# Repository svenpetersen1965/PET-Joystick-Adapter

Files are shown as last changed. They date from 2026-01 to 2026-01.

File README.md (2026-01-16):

# PET-Joystick-Adapter
A C64/VIC-20/Atari Joystick Adapter for the Commodore PET. It supports the Coyote Electronics pin configuration (two joysticks) and the space invader/break put style pin configuration (left, right, fire), found on zimmers.net (https://www.zimmers.net/anonftp/pub/cbm/pet/games/english/joy/index.html).

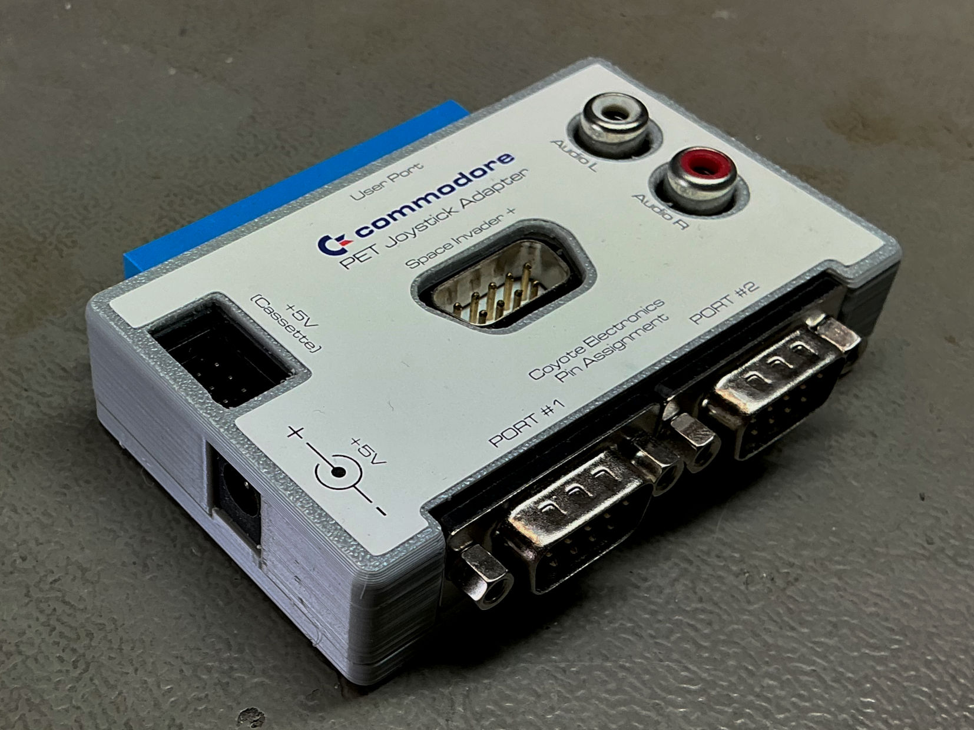
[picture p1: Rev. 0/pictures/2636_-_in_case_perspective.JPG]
PET Joystick Adapter


The Coyote Electronics pin configuration is also called "PET User port adapter" in the VICE emulator, so it is expected to be wide spread. Space Invader + is the completed pin configuration of the previously mentioned games and can also be found on the "stupid PET tricks" adapter. Hence the name. 
All joystick games found in the previously mention source could be played with this joystick adapter.

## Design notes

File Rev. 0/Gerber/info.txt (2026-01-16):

      
       Board: PET_Joystick_Adapter
       Rev.:  0
  
       Files:
       ======
  
       All Gerber files are generated in extended gerber format (RS274X)
       *.TOP        : Film top copper
       *.BOT        :  -"- bottom copper
       *.STC        :  -"- top soldermask 
       *.STS        :  -"- bottom soldermask
       *.PLC        :  -"- silk screen top
       *.PLS        :  -"- silk screen bottom 
       *.DK         : Drills plated Through (Excellon)
       *.NDK        : Drills not plated Through (Excellon)
       *.OUT        : Board outline

       Board Size:
       ===========
       Length     :   77.0 mm
       Width      :   48.0 mm
       Thickness  :   1.6 mm
       Material   :   FR 4
       Copper     :   35 um
       Surface    :   HASL
       
       Remarks:
       ========
       Width >= 8mil
       Distance >= 6mil
       Drill >= 0.35mm

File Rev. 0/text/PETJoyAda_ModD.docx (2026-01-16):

Commodore PET Joystick Adapter Rev. 0

Module Description

# 1 Introduction

This is an adapter for connecting the widespread Commodore C64 or Atari Joysticks to the user port of the PET series computers.

There is no real standard for doing so, thus the most common pin assignments at the user port had to be determined. The main source was the website zimmers.net. The document https://www.zimmers.net/anonftp/pub/cbm/documents/projects/interfaces/pet_joystick.txt shows a pin assignment, that was used for most joystick games, that could be found on the website (https://www.zimmers.net/anonftp/pub/cbm/pet/games/english/joy/index.html). This pin assignment is also found at the original “Coyote Electronics“ joystick adapter“ and it is the one that is used for the „PET“ joystick emulation in the VICE PET emulator.

There is a further pin assignment for „left/right/fire“ games, that can also be found on the said website, which is not identical to the first pin assignment. The up/down directions are not defined for most of those games, except “leap frog fix.prg”. The found pin configuration was confirmed by „Stupid PET tricks“ adapter. There it is called “Space Invader +”, thus the name.

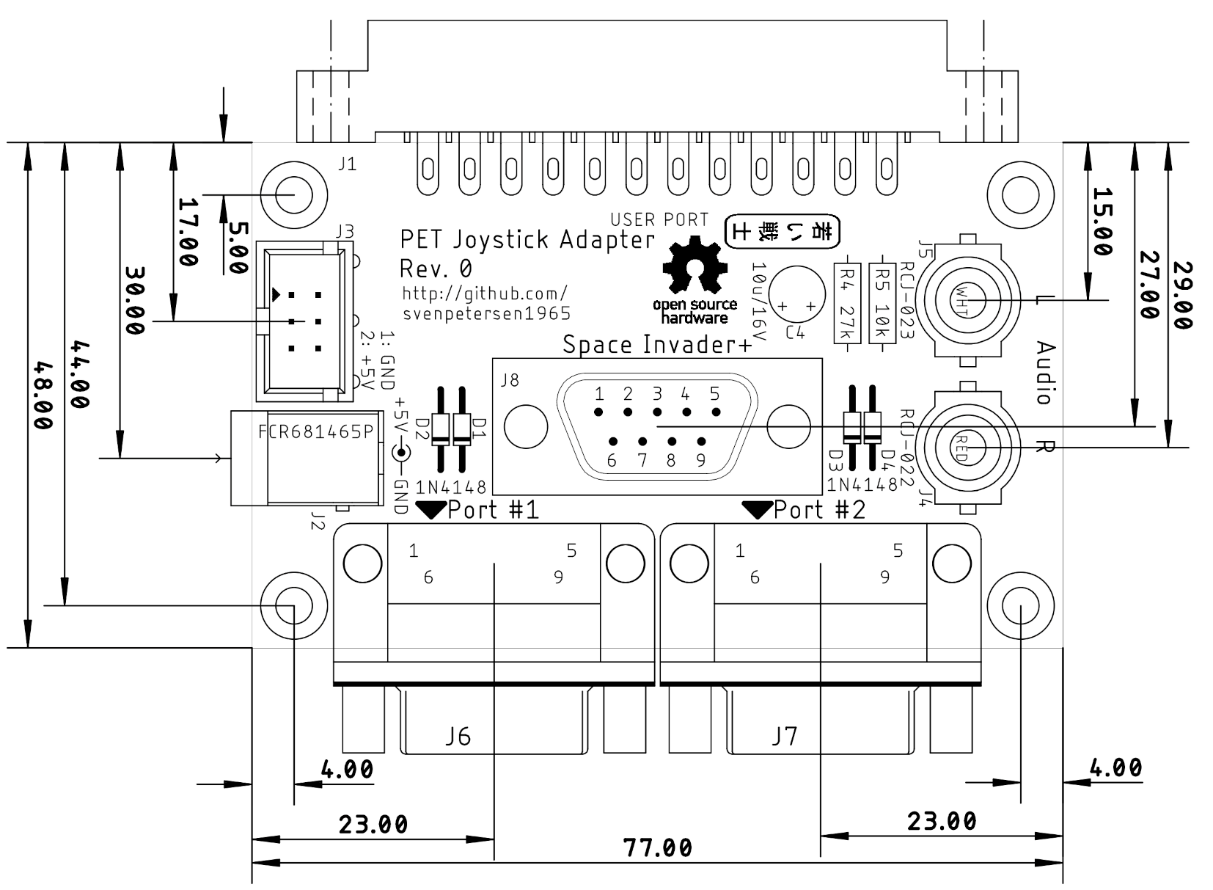
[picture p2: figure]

Figure 1: Dimensions of the PCB

# 2 Pin Assignments

## 2.1 Coyote Electronics

Port | D-Sub Pin | Direction | User Port | Pin
1 | 1 | Up | PA0 | C
| 2 | Down | PA1 | D
| 3 | Left | PA2 | E
| 4 | Right | PA3 | F
| 6 | Fire | PA0 & PA1 (Diodes) | C & D
| 7 | +5V | Not available | -
| 8 | GND | GND | 1, 12, A, N
2 | 1 | Up | PA4 | H
| 2 | Down | PA5 | J
| 3 | Left | PA6 | K
| 4 | Right | PA7 | L
| 6 | Fire | PA4 & PA5 (Diodes) | H & J
| 7 | +5V | Not available | -
| 8 | GND | GND | 1, 12, A, N

## 2.2 Space Invader +

D-Sub Pin | Direction | User Port | Pin
1 | Up | PA2 | E
2 | Down | PA3 | F
3 | Left | PA0 | C
4 | Right | PA1 | D
6 | Fire | PA4 & PA5 (Diodes) | H & J
7 | +5V | Not available | -
8 | GND | GND | 1, 12, A, N

# 3 Further Features

## 3.1 Power Supply

The +5V supply voltage is usually not required, it only serves for powering auto-fire circuits. There are two ways of powering the adapter:

- From the cassette port with the Diagnostic cassette port dongle (https://github.com/svenpetersen1965/C64-Diagnostic-Rev.-586220-Harness/tree/master/Diag586220_Harness/Diag586220_Cassette_Port)
- Via the barrel connector (5.5mm/2.5mm).

## 3.2 Cassette Port Connector

Pin | Signal | Signal | Pin
1 | GND | +5V | 2
3 | n.c. | n.c. | 4
5 | n.c. | n.c. | 6

## 3.3 Barrel Connector

5.5mm/2.5mm

D-Sub Pin | Direction
Center | +5V
Ring | GND

## 3.4 Audio Output

The wide spread PET audio output from port pin CB2 is divided with a 27kΩ/10kΩ voltage divider. The ratio is about 1:4, the output voltage is approximately 1.25Vpp (0.615VRMS Þ-4dBU). In case a level of -10dBU is desired, R4 (27kΩ) can be replaced with a 62kΩ resistor. A capacitor provides DC decoupling. Both, the left and the right output channel are tied together, so stereo speakers can both be driven.

# 4 Gallery

## 4.1 PCB

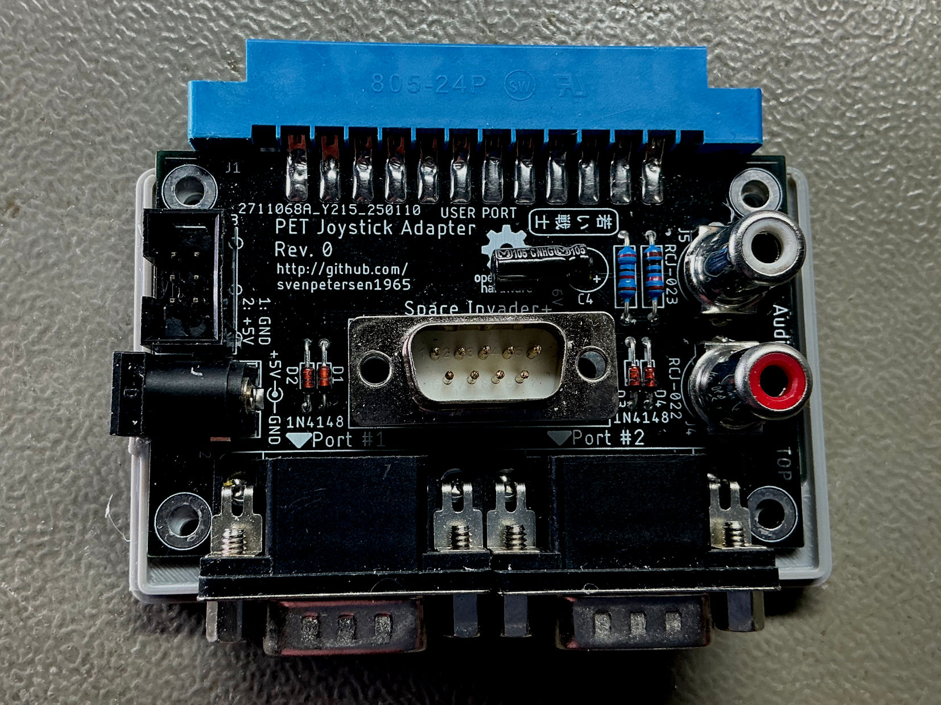
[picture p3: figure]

Figure 2: Top side of the PCB

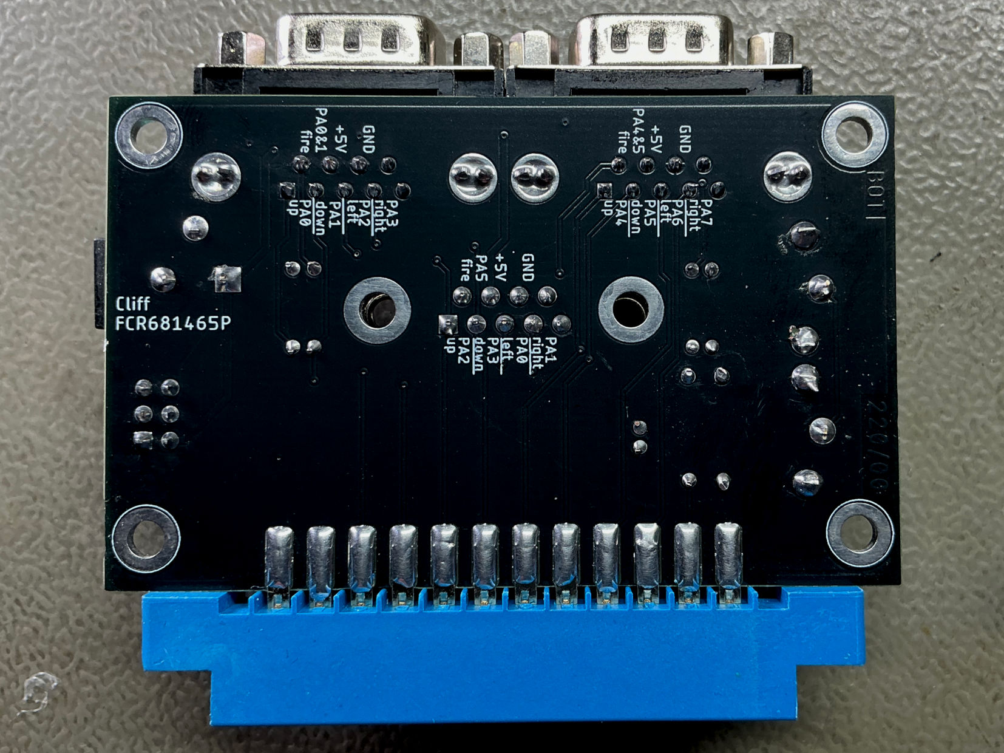
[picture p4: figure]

Figure 3: Bottom side of the PCB

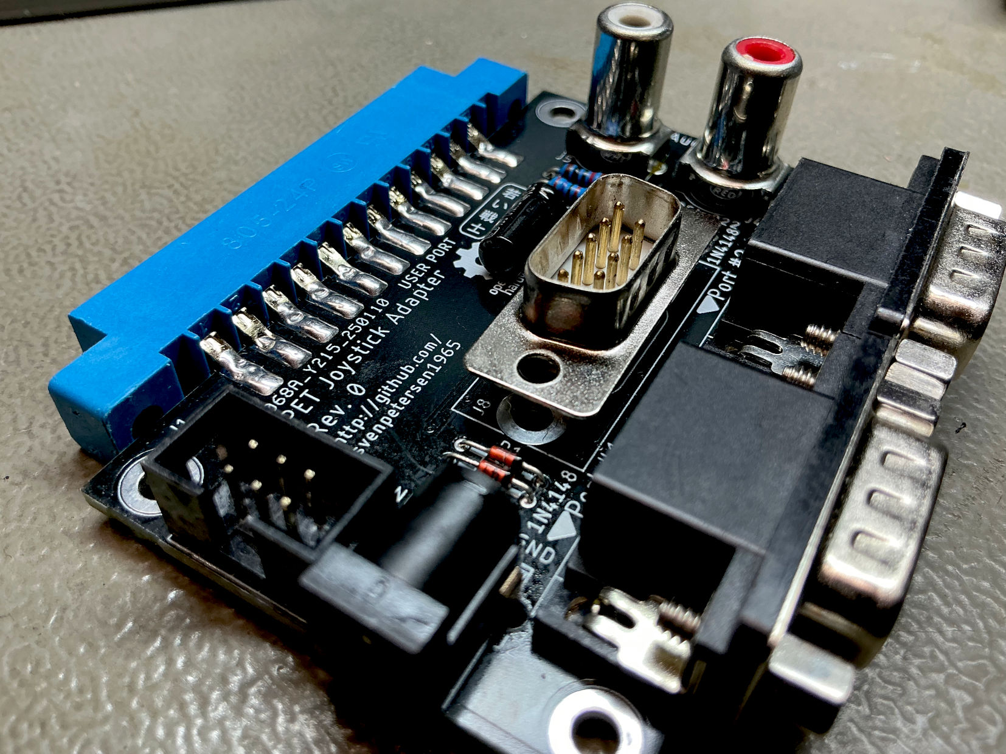
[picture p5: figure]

Figure 4: Soldering of the user port connector

The edge connector should be soldered flat on the solder side (Figure 3) and with bent pins on the top side (Figure 4).

## 4.2 Full assembly


Figure 5: Joystick Adapter with 3D printed case and label

# 5 Revision History

## Rev. 0

- Working prototype

PETJoyAda_ModD.docx 16.01.2026 12:57 Drafted by Sven Petersen Page 5 of 5 Doc.-No.: 220-6-01-00

PETJoyAda_ModD.docx 16.01.2026 12:57 Drafted by Sven Petersen Page 1 of 5 Doc.-No.: 220-6-01-00

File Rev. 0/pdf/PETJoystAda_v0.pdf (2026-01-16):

# Project Documentation

## PET Joystick Adapter

## Project number: 220

## Revision: 0

## Date: 04.01.2025

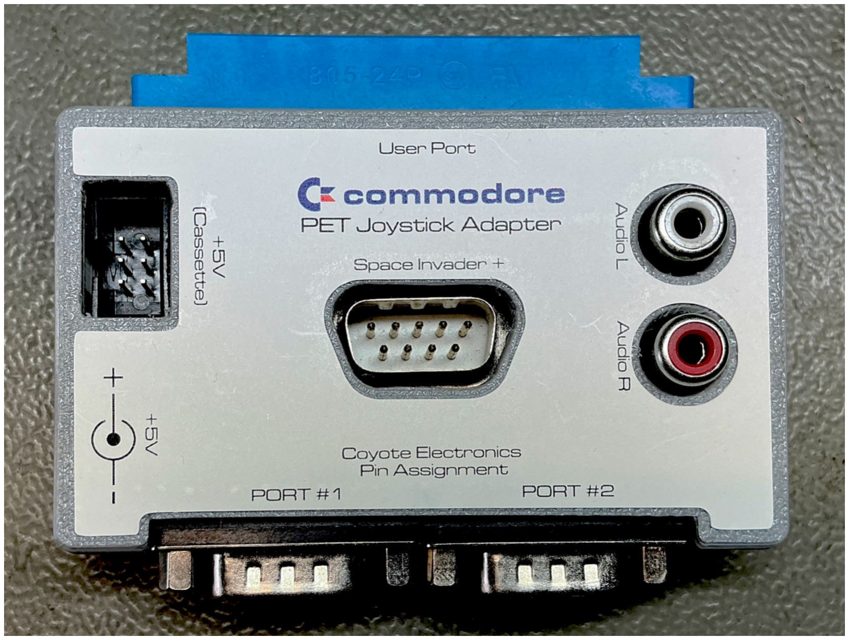
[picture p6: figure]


PETJoyAda_ModD.docx | | 16.01.2026 12:57
Drafted by Sven Petersen | Page 1 of 5 | Doc.-No.: 220-6-01-00

### Commodore PET Joystick Adapter Rev. 0

### Module Description

## 1 Introduction

This is an adapter for connecting the widespread Commodore C64 or Atari Joysticks to the user port of the PET series computers.

There is no real standard for doing so, thus the most common pin assignments at the user port had to be determined. The main source was the website zimmers.net. The document https://www.zimmers.net/anonftp/pub/cbm/documents/projects/interfaces/pet_joystick.txt shows a pin assignment, that was used for most joystick games, that could be found on the website (https://www.zimmers.net/anonftp/pub/cbm/pet/games/english/joy/index.html). This
pin assignment is also found at the original “Coyote Electronics“ joystick adapter“ and it is the one that is used for the „PET“ joystick emulation in the VICE PET emulator.
There is a further pin assignment for „left/right/fire“ games, that can also be found on the said
website, which is not identical to the first pin assignment. The up/down directions are not defined for most of those games, except “leap frog fix.prg”. The found pin configuration was
confirmed by „Stupid PET tricks“ adapter. There it is called “Space Invader +”, thus the name.

Figure 1: Dimensions of the PCB

PETJoyAda_ModD.docx | | 16.01.2026 12:57
Drafted by Sven Petersen | Page 2 of 5 | Doc.-No.: 220-6-01-00

## 2 Pin Assignments

### 2.1 Coyote Electronics

Port | D-Sub Pin | Direction | User Port | Pin
1 | 1 | Up | PA0 | C
| 2 | Down | PA1 | D
| 3 | Left | PA2 | E
| 4 | Right | PA3 | F
| 6 | Fire | PA0 & PA1 (Diodes) | C & D
| 7 | +5V | Not available | -
| 8 | GND | GND | 1, 12, A, N
2 | 1 | Up | PA4 | H
| 2 | Down | PA5 | J
| 3 | Left | PA6 | K
| 4 | Right | PA7 | L
| 6 | Fire | PA4 & PA5 (Diodes) | H & J
| 7 | +5V | Not available | -
| 8 | GND | GND | 1, 12, A, N

### 2.2 Space Invader +

D-Sub Pin | Direction | User Port | Pin
1 | Up | PA2 | E
2 | Down | PA3 | F
3 | Left | PA0 | C
4 | Right | PA1 | D
6 | Fire | PA4 & PA5 (Diodes) | H & J
7 | +5V | Not available | -
8 | GND | GND | 1, 12, A, N

## 3 Further Features

### 3.1 Power Supply

The +5V supply voltage is usually not required, it only serves for powering auto-fire circuits. There are two ways of powering the adapter:

- From the cassette port with the Diagnostic cassette port dongle (https://github.com/svenpetersen1965/C64-Diagnostic-Rev.-586220-Harness/tree/master/Diag586220_Harness/Diag586220_Cassette_Port) (https://github.com/svenpetersen1965/C64-Diagnostic-Rev.-586220-Harness/tree/master/Diag586220_Harness/Diag586220_Cassette_Port)
- Via the barrel connector (5.5mm/2.5mm).

### 3.2 Cassette Port Connector

Pin | Signal | Signal | Pin
1 | GND | +5V | 2
3 | n.c. | n.c. | 4
5 | n.c. | n.c. | 6

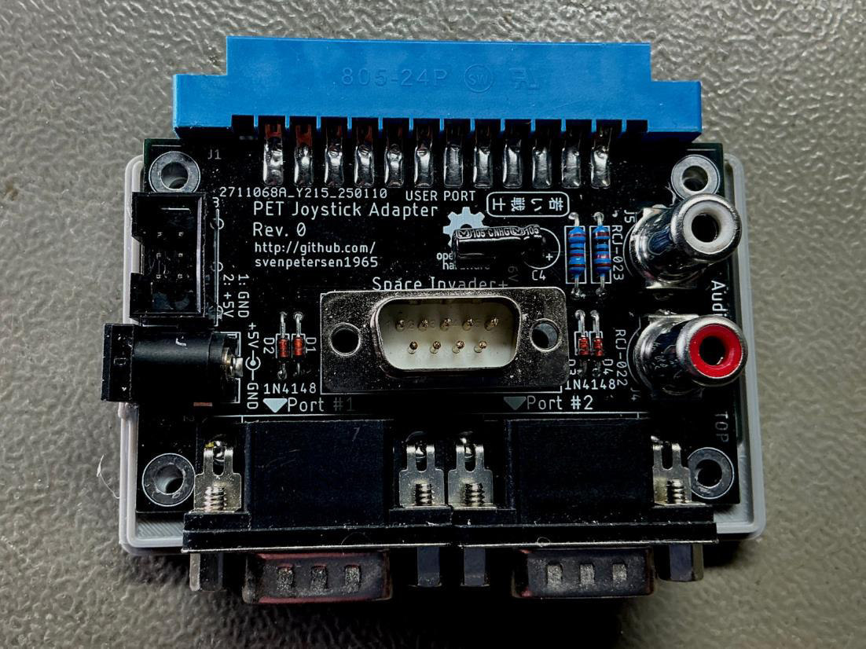
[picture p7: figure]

PETJoyAda_ModD.docx | | 16.01.2026 12:57
Drafted by Sven Petersen | Page 3 of 5 | Doc.-No.: 220-6-01-00

### 3.3 Barrel Connector

5.5mm/2.5mm

D-Sub Pin | Direction
Center | +5V
Ring | GND

### 3.4 Audio Output

The wide spread PET audio output from port pin CB2 is divided with a 27kΩ/10kΩ voltage divider. The ratio is about 1:4, the output voltage is approximately 1.25Vpp (0.615VRMS Þ-4dBU). In case a level of -10dBU is desired, R4 (27kΩ) can be replaced with a 62kΩ resistor. A capacitor provides DC decoupling. Both, the left and the right output channel are tied together, so stereo speakers can both be driven.

## 4 Gallery

### 4.1 PCB

Figure 2: Top side of the PCB

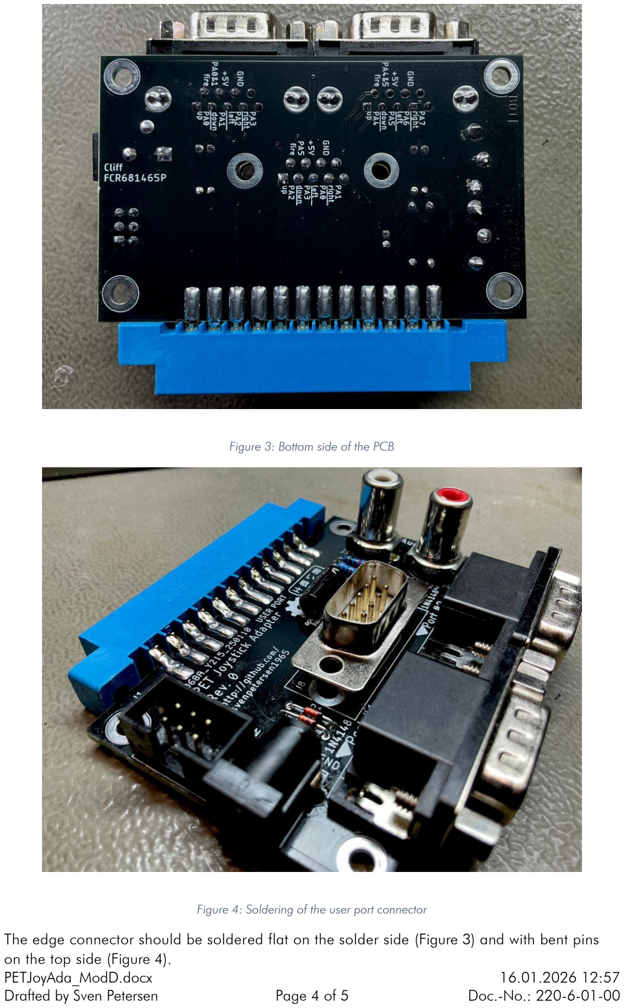
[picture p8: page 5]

PETJoyAda_ModD.docx | | 16.01.2026 12:57
Drafted by Sven Petersen | Page 4 of 5 | Doc.-No.: 220-6-01-00

Figure 3: Bottom side of the PCB

Figure 4: Soldering of the user port connector

The edge connector should be soldered flat on the solder side (Figure 3) and with bent pins on the top side (Figure 4).

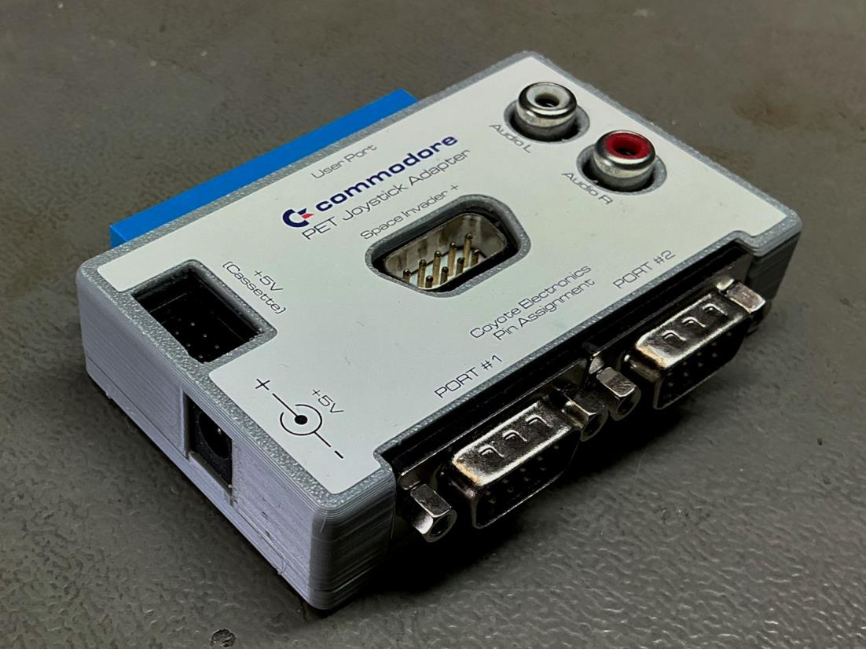
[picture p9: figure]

PETJoyAda_ModD.docx | | 16.01.2026 12:57
Drafted by Sven Petersen | Page 5 of 5 | Doc.-No.: 220-6-01-00
4.2 | Full assembly

## 5 Revision History

### Rev. 0

- Working prototype

Figure 5: Joystick Adapter with 3D printed case and label

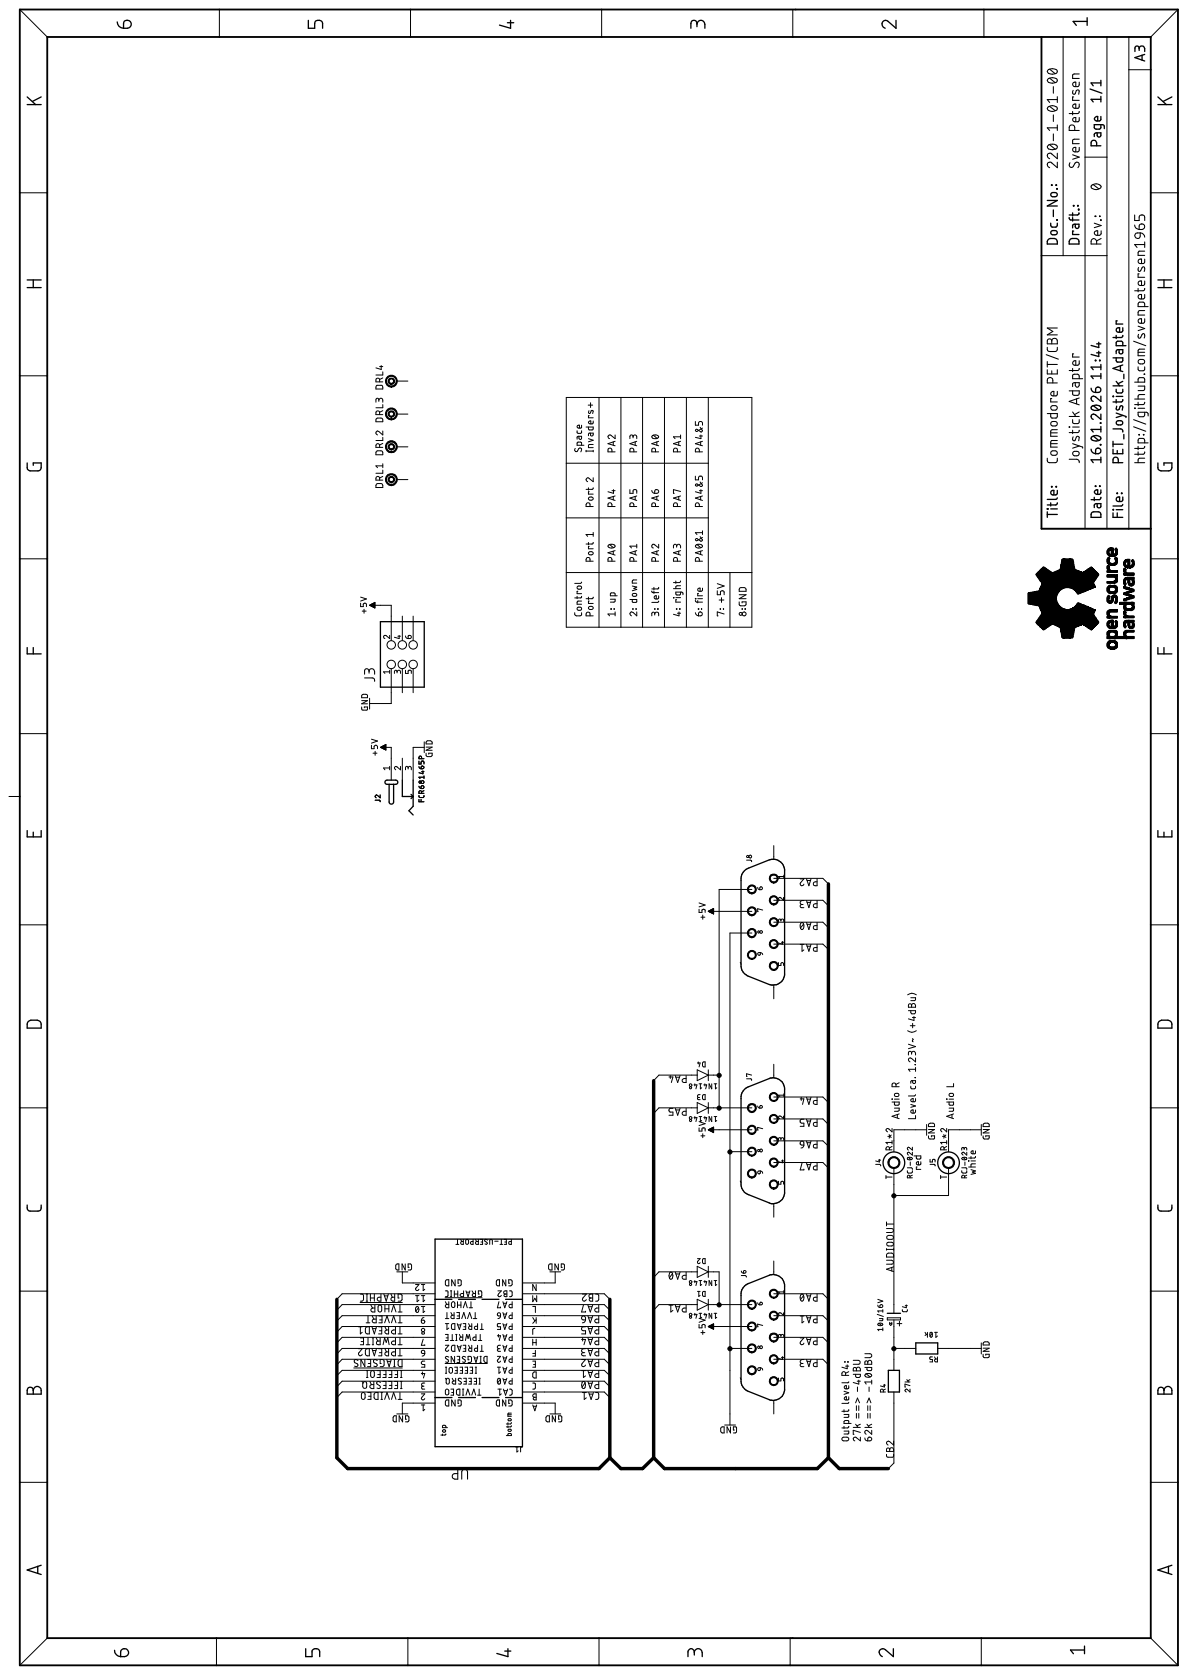
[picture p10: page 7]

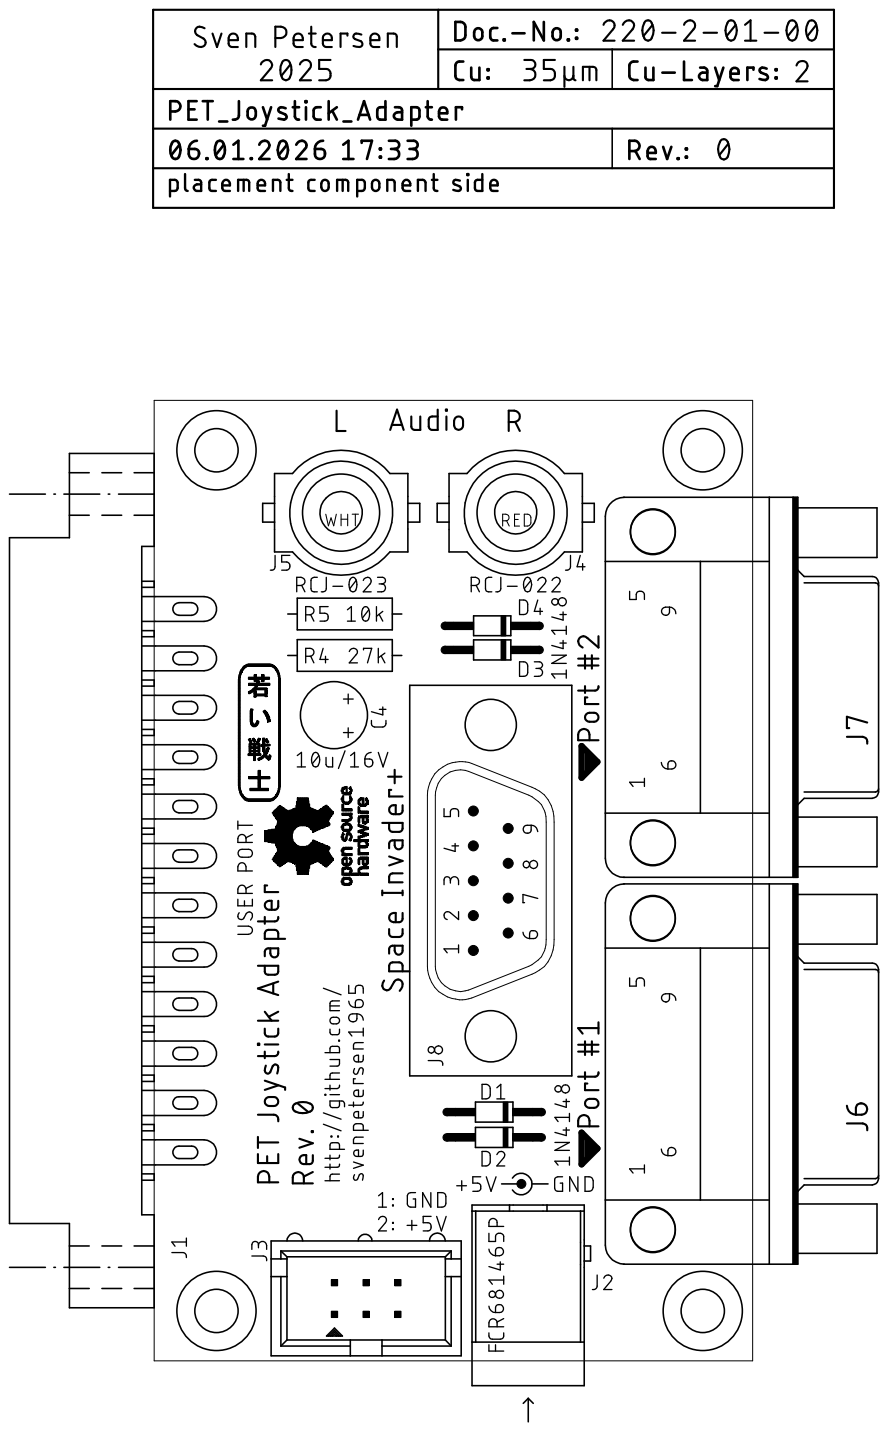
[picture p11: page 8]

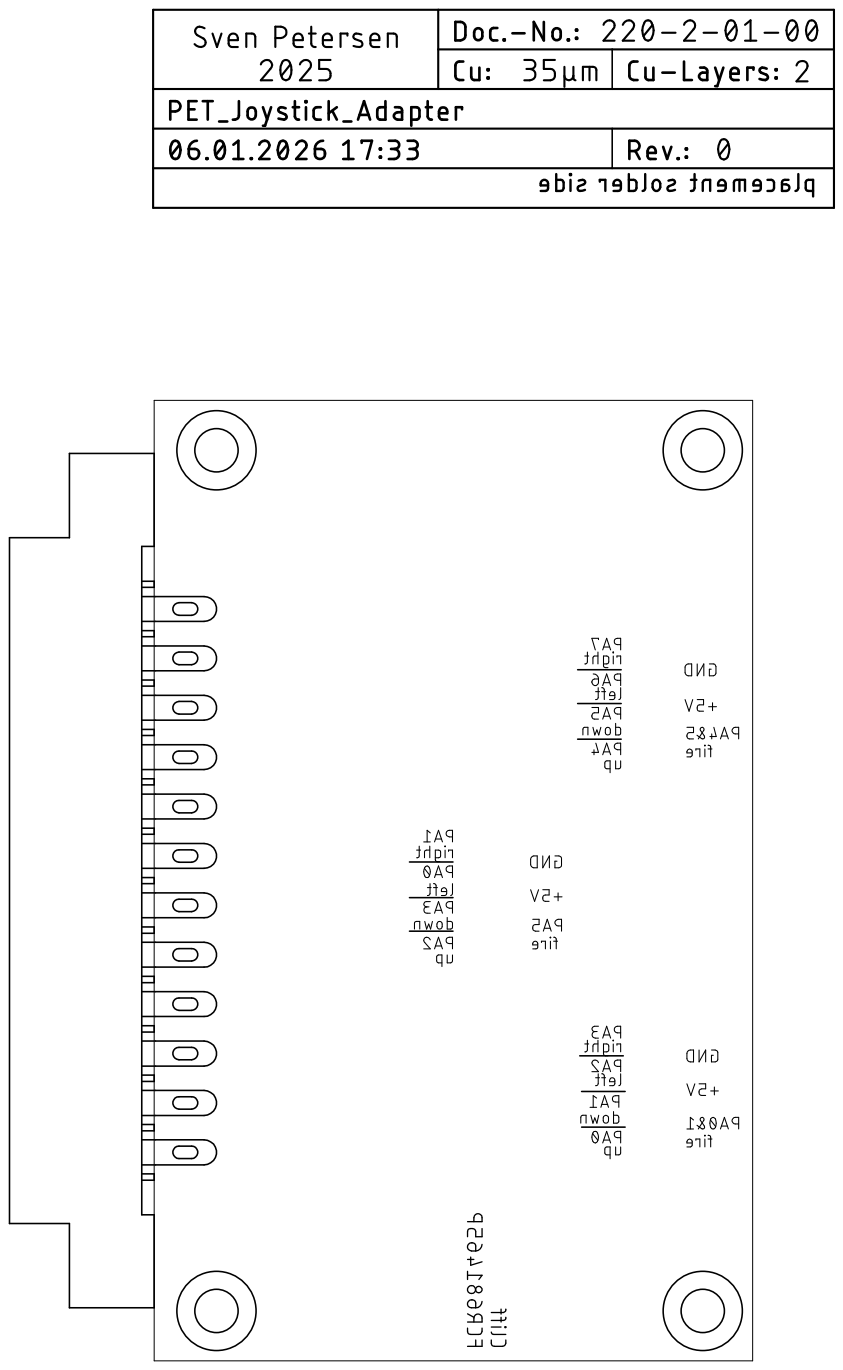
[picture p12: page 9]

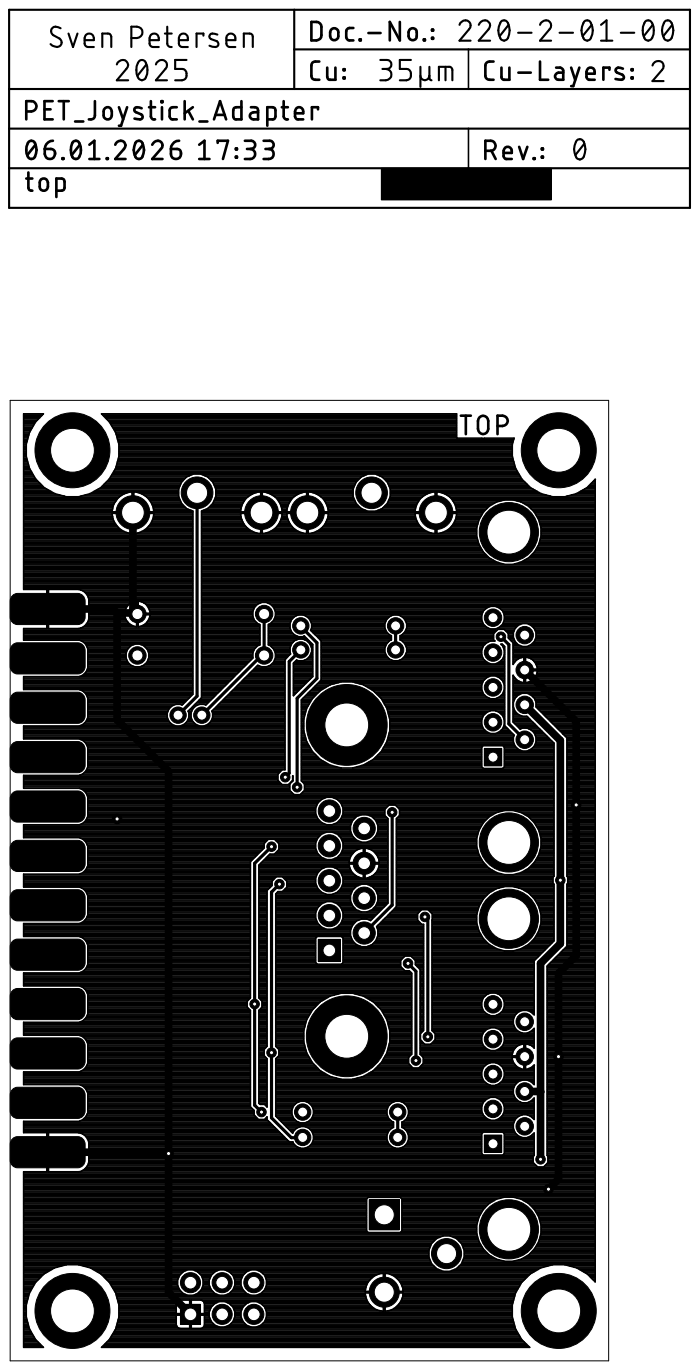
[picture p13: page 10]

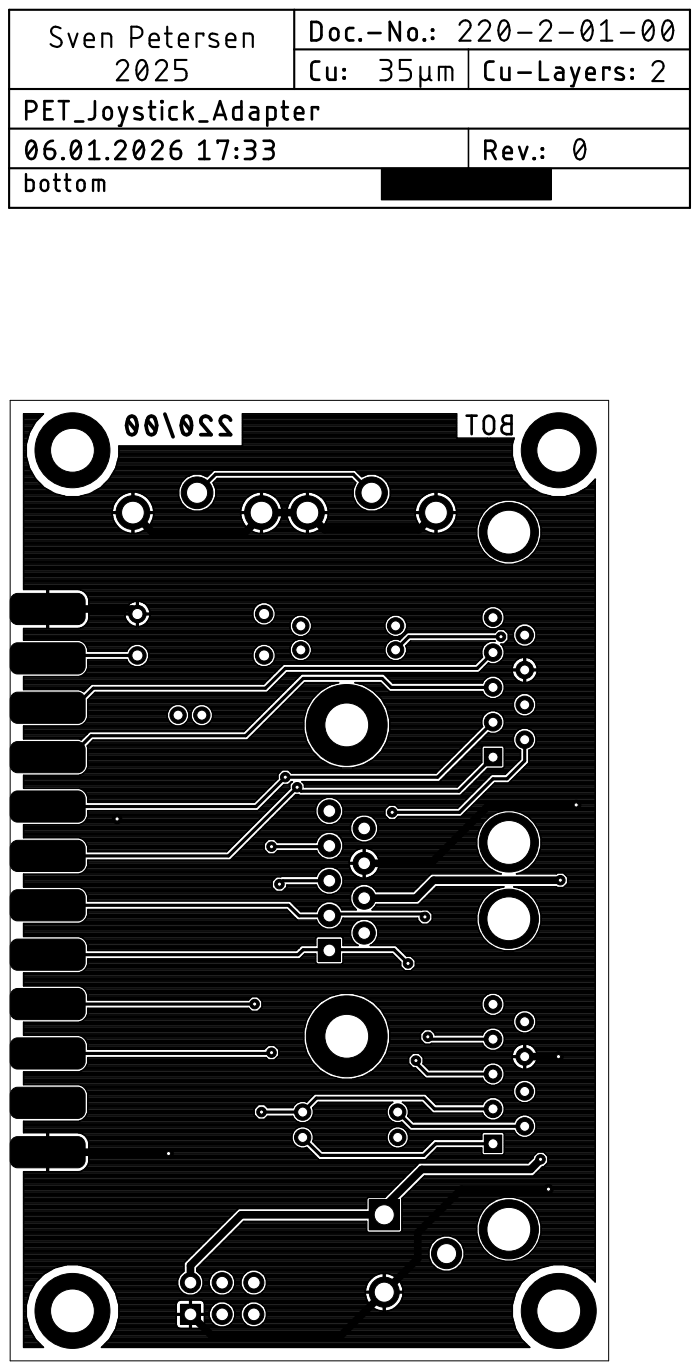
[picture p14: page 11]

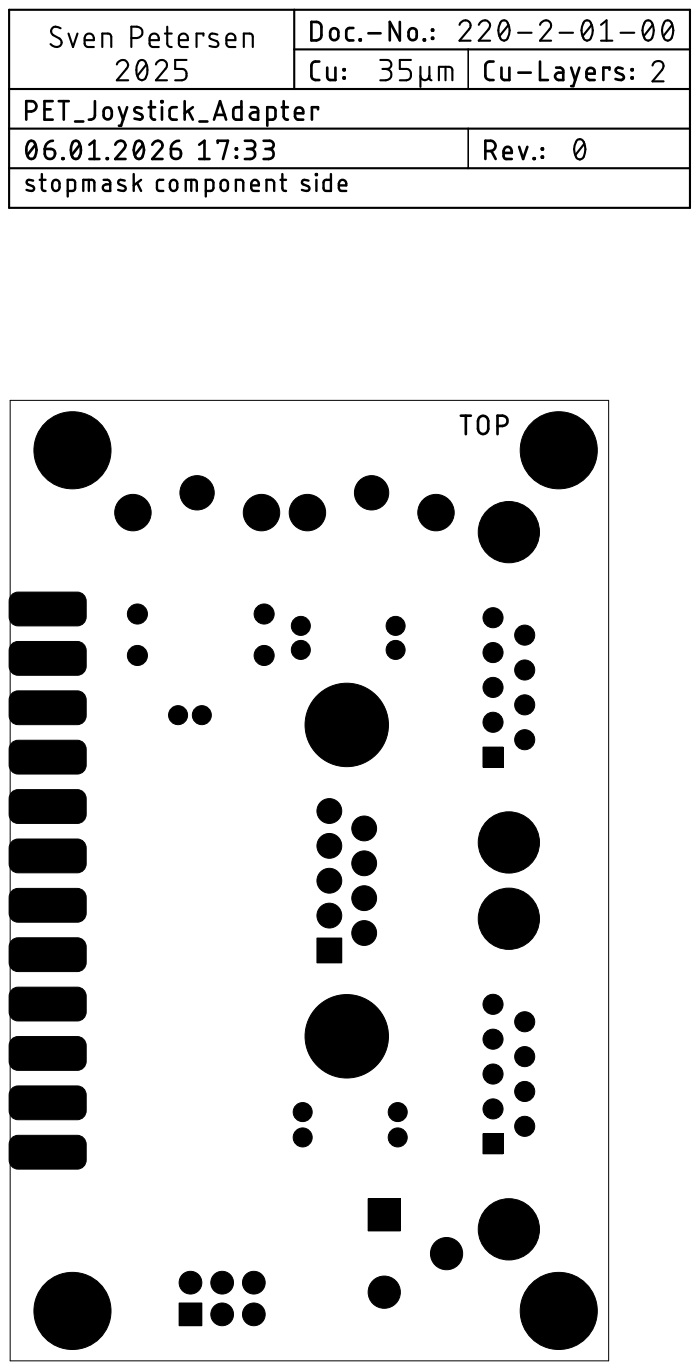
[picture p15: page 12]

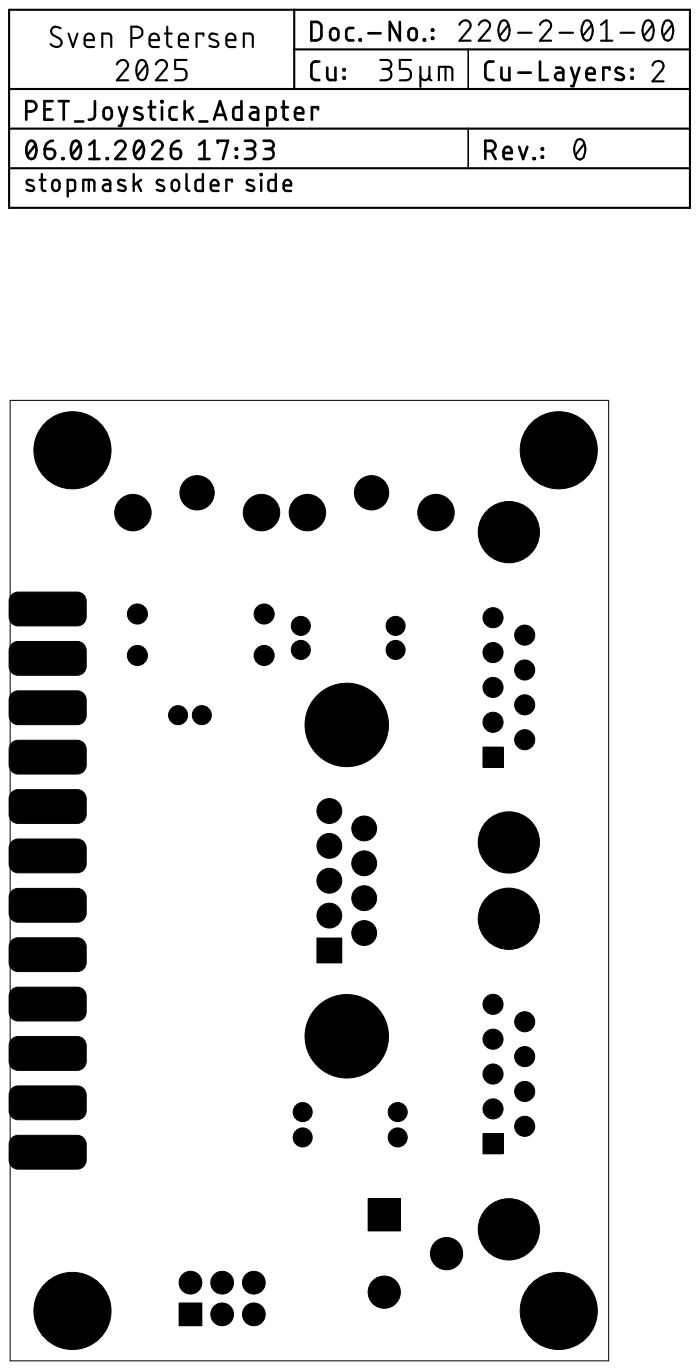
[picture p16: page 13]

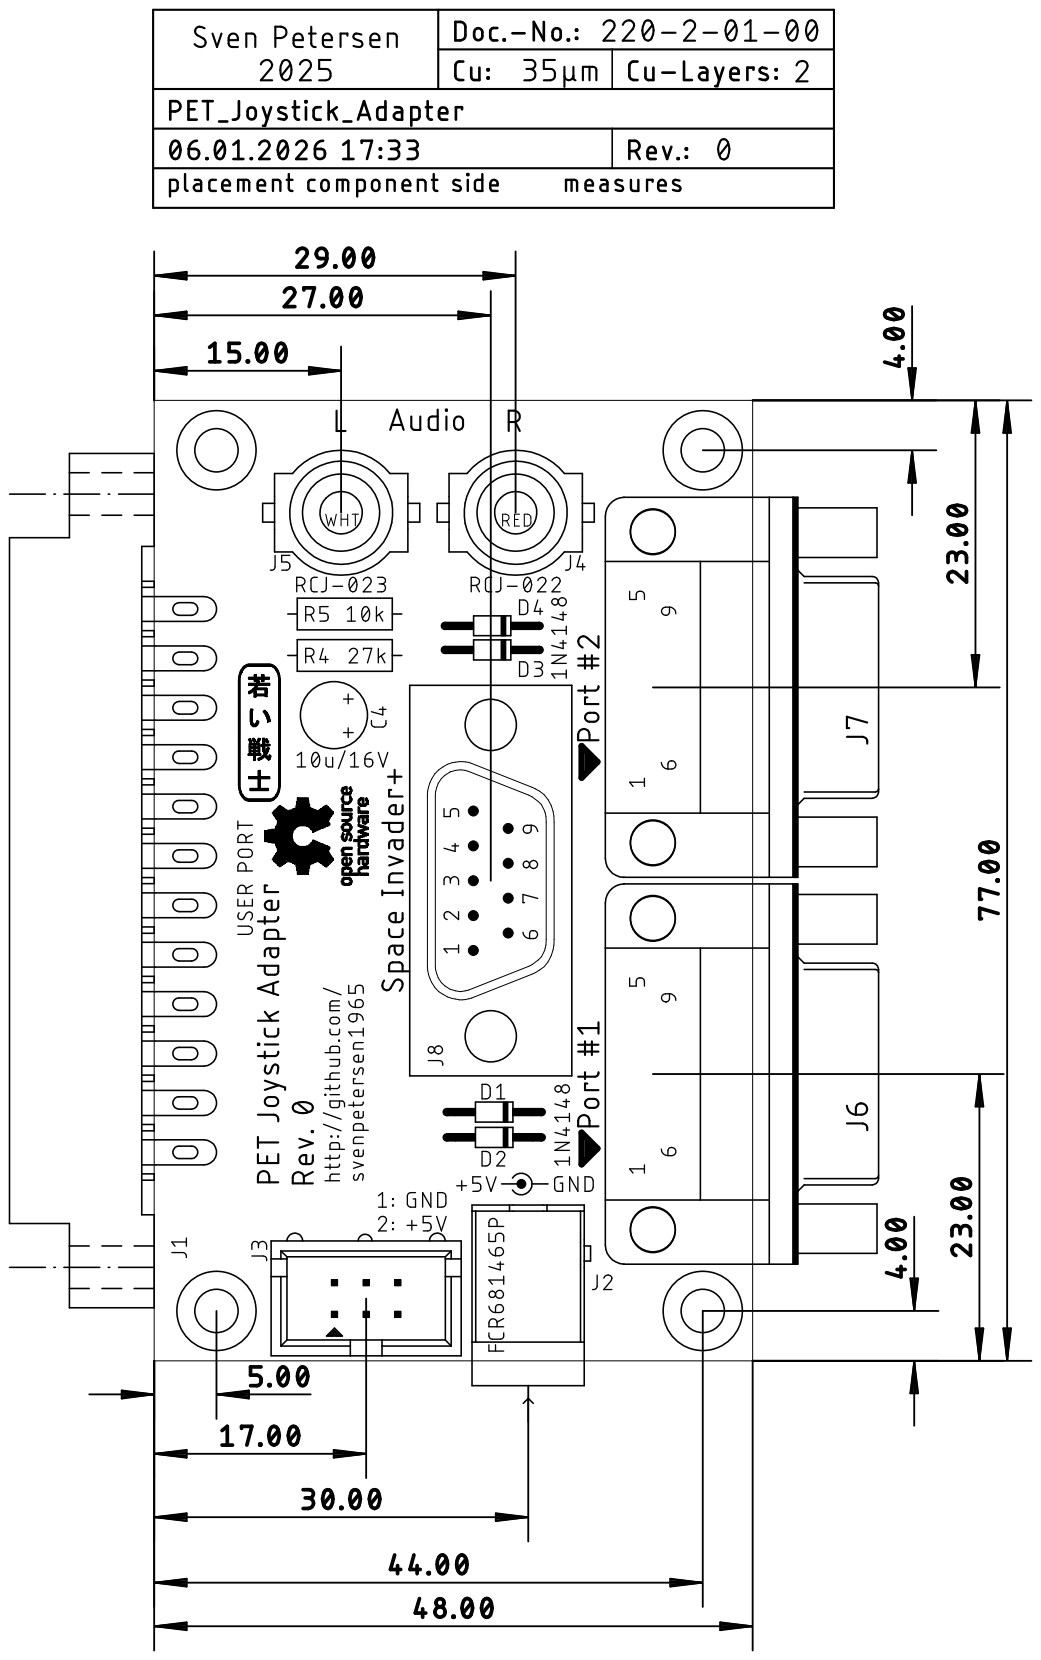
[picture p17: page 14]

PETJoyAda_Test .docx | | 16.01.2026 12:01
Drafted by Sven Petersen | Page 1 of 3 | Doc.-No.: 220-6-01-00

### Commodore PET Joystick Adapter Rev. 0

### Testing

## Test Setup

- Commodore CBM3016 computer
- Three C64 Joysticks
- PET Joystick Adapter Rev. 0
- SD2PET future with software
- Cassette Port Dongle from the C64 diagnostic harness for supplying powering
- C64 Control Port Switch/Rapid Fire
- FNRSI
- PC speakers

## Test Execution

The Joysticks were connected to all joystick/DSub connectors on the joystick adapter. The user port bits were displayed with the test software uptest.prg.

Coyote Electronics:

Port | Direction | User Port | Result
1 | Up | PA0 | ☑
| Down | PA1 | ☑
| Left | PA2 | ☑
| Right | PA3 | ☑
| Fire | PA0 & PA1 | ☑
2 | Up | PA4 | ☑
| Down | PA5 | ☑
| Left | PA6 | ☑
| Right | PA7 | ☑
| Fire | PA4 & PA5 | ☑

Space Invader +:

Direction | User Port | Result
Up | PA2 | ☑
Down | PA3 | ☑
Left | PA0 | ☑
Right | PA1 | ☑
Fire | PA4 & PA5 | ☑

The displayed user port bits were compared to the Coyote Electronics and the Space Invaders+ configuration. All bits were as expected.

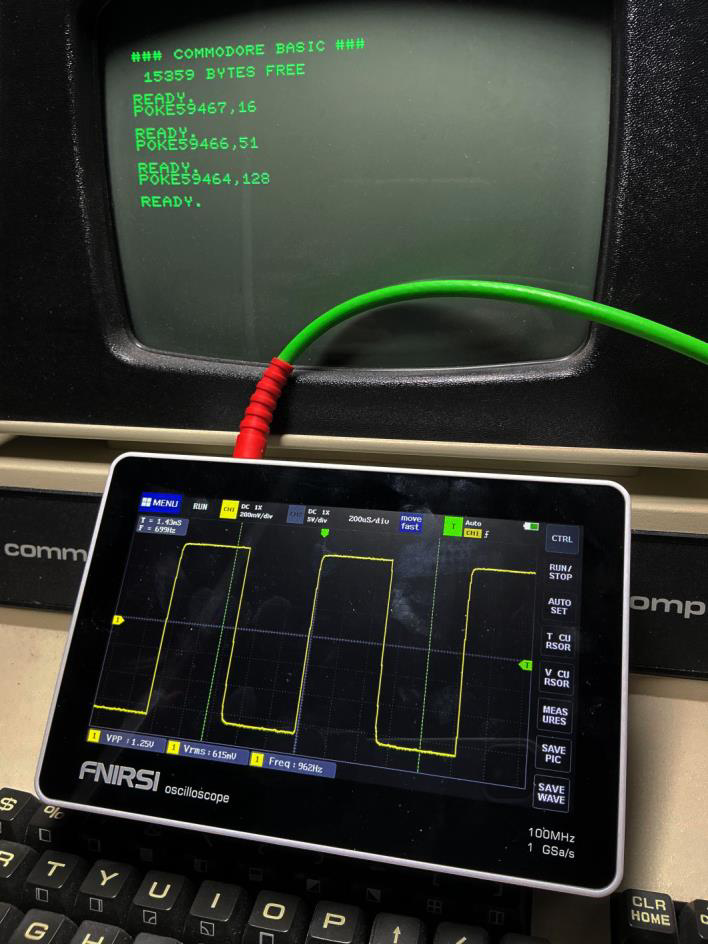
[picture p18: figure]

PETJoyAda_Test .docx | | 16.01.2026 12:01
Drafted by Sven Petersen | Page 2 of 3 | Doc.-No.: 220-6-01-00

The audio outputs were inspected with an oscilloscope. For this purpose, an oscilloscope was connected via an adapter cable and the following basic instruction were executed to generate a waveform on the user port CB2:

POKE59467,16
POKE59466,51
POKE59464,128

The audio output is as desired. The amplitude was 1.25VPP and 615mVRMS, which is -4.2dBV (within the headroom of a -10dBV consumer audio line out). This level is no problem with standard audio equipment. In case this is too hot for your desire, you can replace the 27kΩ resistor in R4 with a 62kΩ resistor to get closer to the -10dBU.

The +5V supply was tested with an auto-fire circuit, which was connected to Port #1 and Port #2. A power supply was connected to the barrel connector and the auto-fire was powered properly. The same was tested while powering the device via the 6p pin header from the cassette port.

Finally, the games from zimmers.net were tested with the joystick adapter.

Game | Pin Configuration | Note
afo.prg | Coyote Electronics, port #1
arrow.prg | Coyote Electronics, port #1
bomber.prg | Coyote Electronics, port #1
break-out.prg | Coyote Electronics, port #1

Figure 1: CB2 audio wave form

PETJoyAda_Test .docx | | 16.01.2026 12:01
Drafted by Sven Petersen | Page 3 of 3 | Doc.-No.: 220-6-01-00
breakout.prg | Coyote Electronics, port #1
brickwall.prg | Coyote Electronics, port #1
cosmiads uni.prg | Space Invaders+:LEFT=PA0, RIGHT=PA1, FIRE=PA5. | POKE 2571,79 before RUN for joystick on user port.
galaxy invdr joy.prg | Space Invaders+ (left/right/fire)
invaders.prg | Space Invaders+ LEFT=PA0, RIGHT=PA1, FIRE=PA5.
joystick_test.prg | Coyote Electronics, port #1&2
leap frog fix.prg | Space Invaders+ (4 dir)
pong joysticks.prg | port #1 & #2 (left/right: moves down/up)
print_racer.prg | Coyote Electronics, port #1
shark.prg | Coyote Electronics, port #1
space war.prg | ? | No joystick function found
star spores.prg | Space Invaders+
zap.prg | Coyote Electronics, port #1

Except space war.prg, all games were playable with one of either joystick pin configurations. It is not clear, if this program requires a poke to activate the joystick (like cosmiads uni) or is it does not even support joysticks. There was no reaction on any of the three ports, which actually should have been the case, since every user port bit can be manipulated this way.

## Conclusion

The PET Joystick Adapter Rev. 0 is functional with the programs on zimmers.net, that support joystick and it seems, that the two pin configurations are the most popular ones.

Pos. Qty Value Footprint Ref.-No. Comment

1 1 220-2-01-00 2 Layer PCB Rev. 0 2 layer, Cu 35µ, HASL, 48.0mm x 77.0mm, 1.6mm FR4

2 1 2x3 box header, 2.54mm 2X03WV J3 e.g. Reichelt WSL 6G. Option: Power from tape

3 2 Dsub, 9p, male, horizontal DS9M-H J6, J7 e.g. Reichelt BKL 10120037
4 1 Dsub, 9p, male, vertical DS09M-V J8 e.g. Reichelt D-SUB ST 09P

5 1 10k R-10 R5 1/4W, 1% or better

6 1 10u/16V C5,0/2,0 C4 aluminum electrolytic, ∅5.0mm/pitch 2.0mm 105°C,

l=11mm, e.G. Reichelt RD1C106M05011180

7 4 1N4148 D1, D2, D3, D4 standard silicon diode

8 1 27k R-10 R4 1/4W, 1% or better. 27k for -4dBU or 62k for -10dBU

audio level.

9 1 FCR681465P FCR681465P J2 Cliff. 2,5mm/5.5mm barrel connector. E.g. Reichelt CLIFF

FCR681465P Option: external Power 10 1 Edge connector, 2x12,

3.96mm

USERPORT J1 edge connector, C64 user port, Ali Express, "series 805" or

other

11 1 RCJ-022 RCJ-02X J4 CUI Inc., RCA jack, vertical, red. Mouser: 490-RCJ-022,
Digikey: CP-1407-ND. Alternative part: Keystone 577

12 1 RCJ-023 RCJ-02X J5 CUI Inc., RCA jack, vertical, white. Mouser: 490-RCJ-023,
Digikey: CP-1408-ND. Alternative part: Keystone 584

## Commodore PET Joystick Adapter Rev. 0

## Bill of Material Rev. 0.0

PETJoyst_BOM_v0_0.xlsx

Drafted by Sven Petersen Page 1 of 1

16.01.2026 12:12
Doc.No.: 220-5-01-00.0

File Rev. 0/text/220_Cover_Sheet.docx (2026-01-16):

Project Documentation

PET Joystick Adapter

Project number: 220

Revision: 0

Date: 04.01.2025

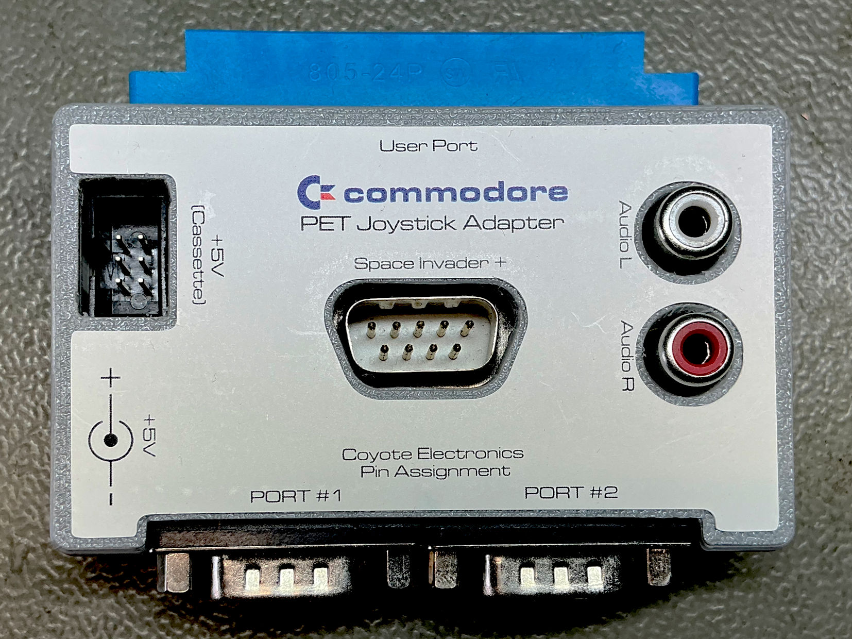
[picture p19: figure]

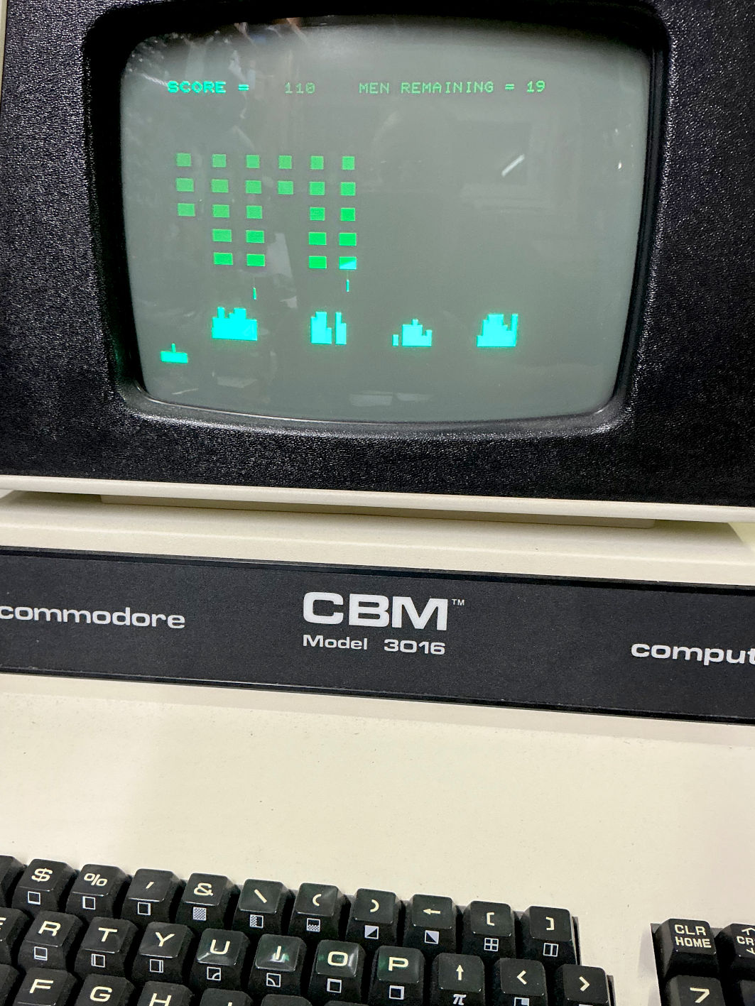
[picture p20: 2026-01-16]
Rev. 0/pictures/2668_-_GALAXY_INVADER_PRG.JPG

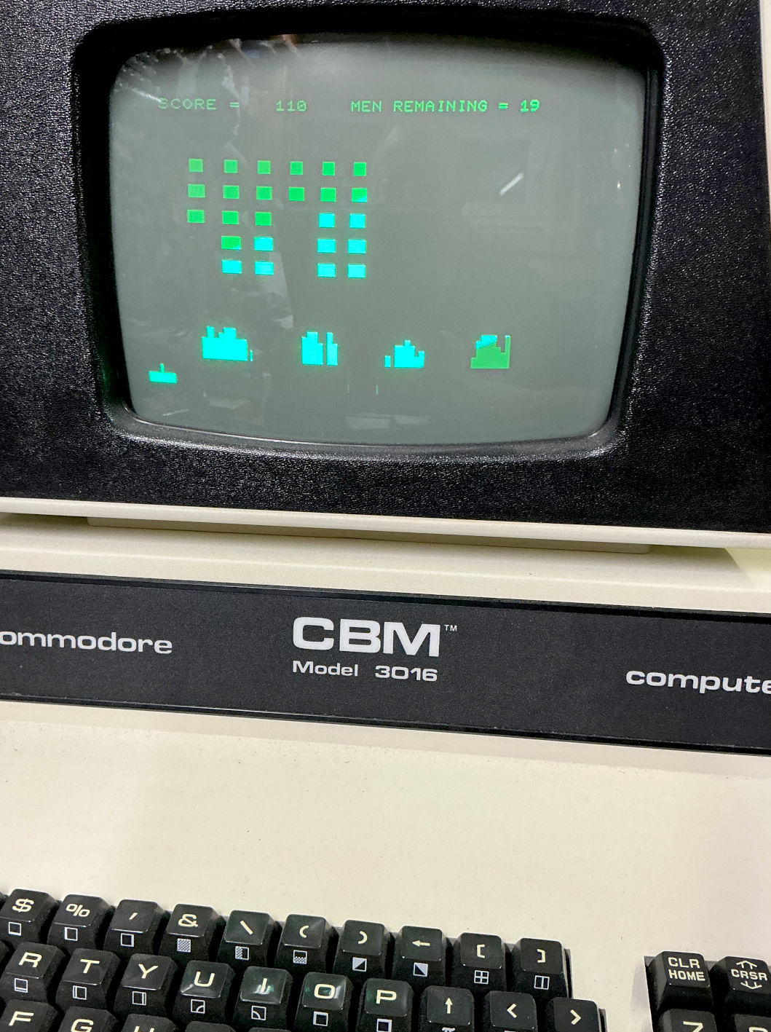
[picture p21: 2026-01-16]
Rev. 0/pictures/2667_-_GALAXY_INVADER_PRG.JPG

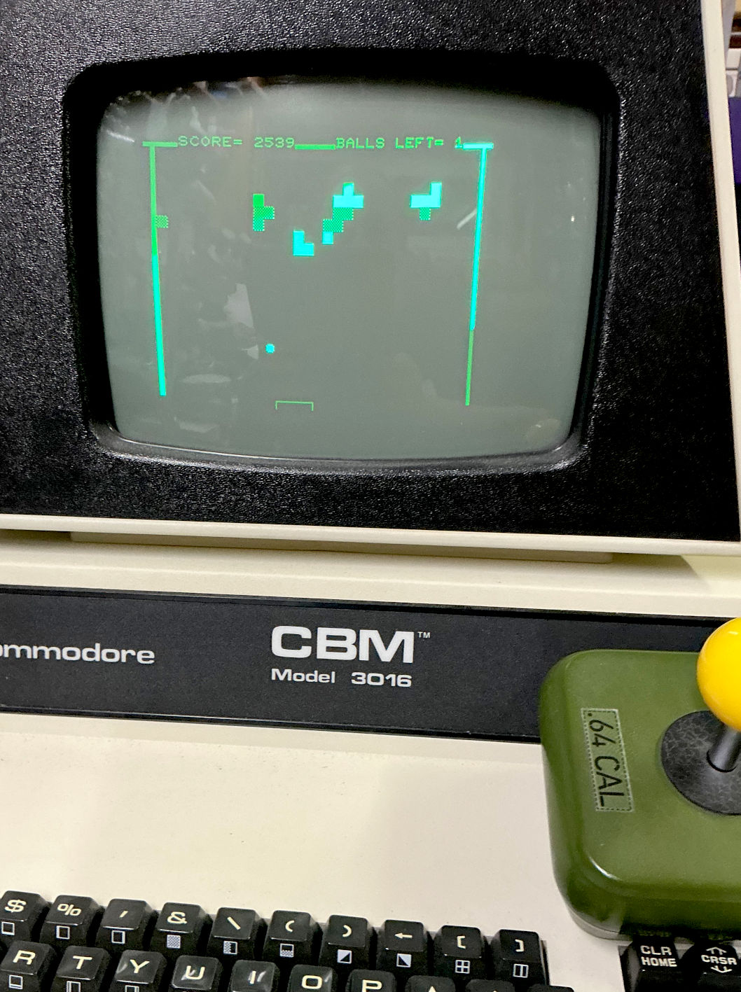
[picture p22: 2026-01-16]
Rev. 0/pictures/2669_-_BREAKOUT_PRG.JPG

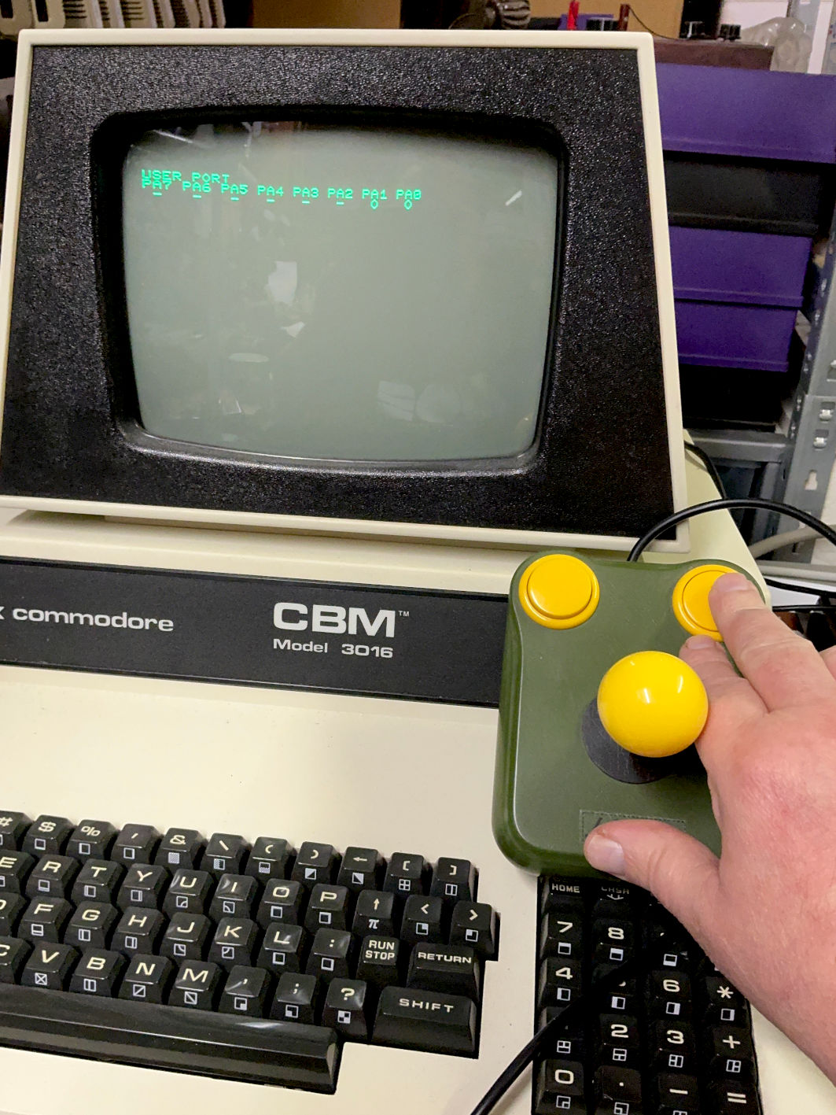
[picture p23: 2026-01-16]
Rev. 0/pictures/2664_-_UPTEST_PRG.JPG

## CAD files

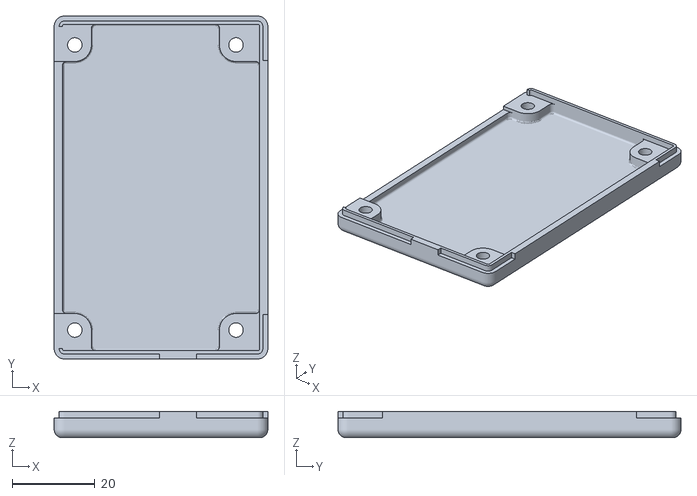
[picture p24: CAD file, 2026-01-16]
Case/Rev. 0/stl/bottom_shell.stl
51.7 x 83.0 x 6.40

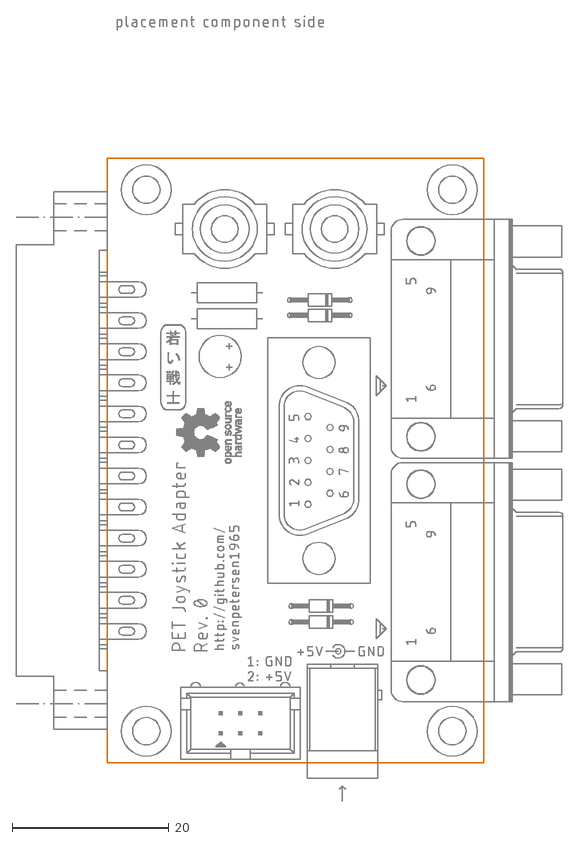
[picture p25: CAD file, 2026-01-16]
Rev. 0/dxf/PET_Joystick_Adapter.dxf
69.7 x 100.0

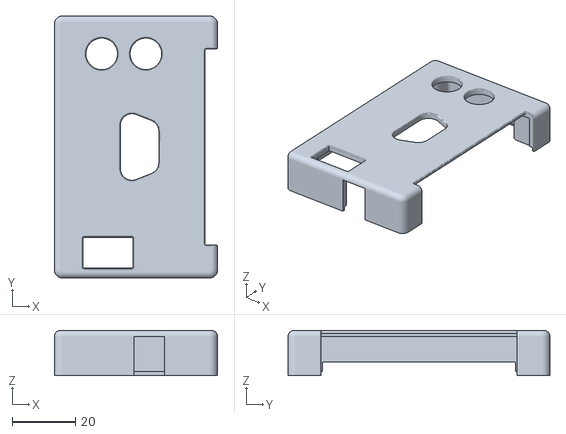
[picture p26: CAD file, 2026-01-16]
Case/Rev. 0/stl/top_shell.stl
51.7 x 83.0 x 14.4

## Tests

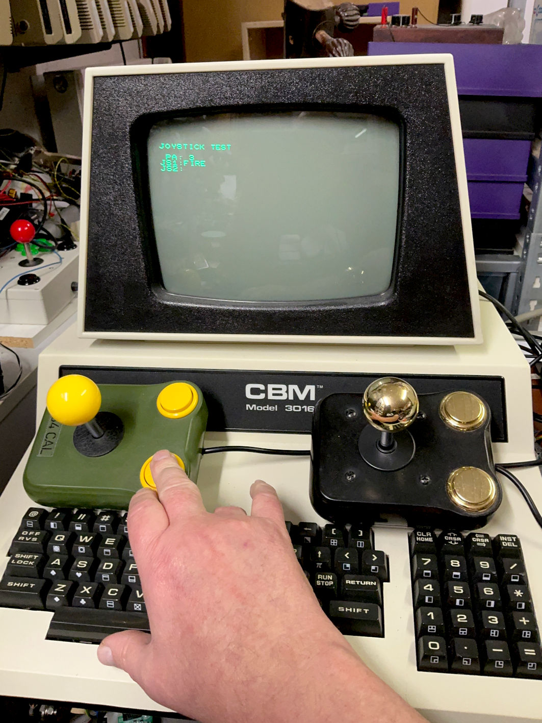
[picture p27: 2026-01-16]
Rev. 0/pictures/2654_-_Joystick_Test_prg.JPG

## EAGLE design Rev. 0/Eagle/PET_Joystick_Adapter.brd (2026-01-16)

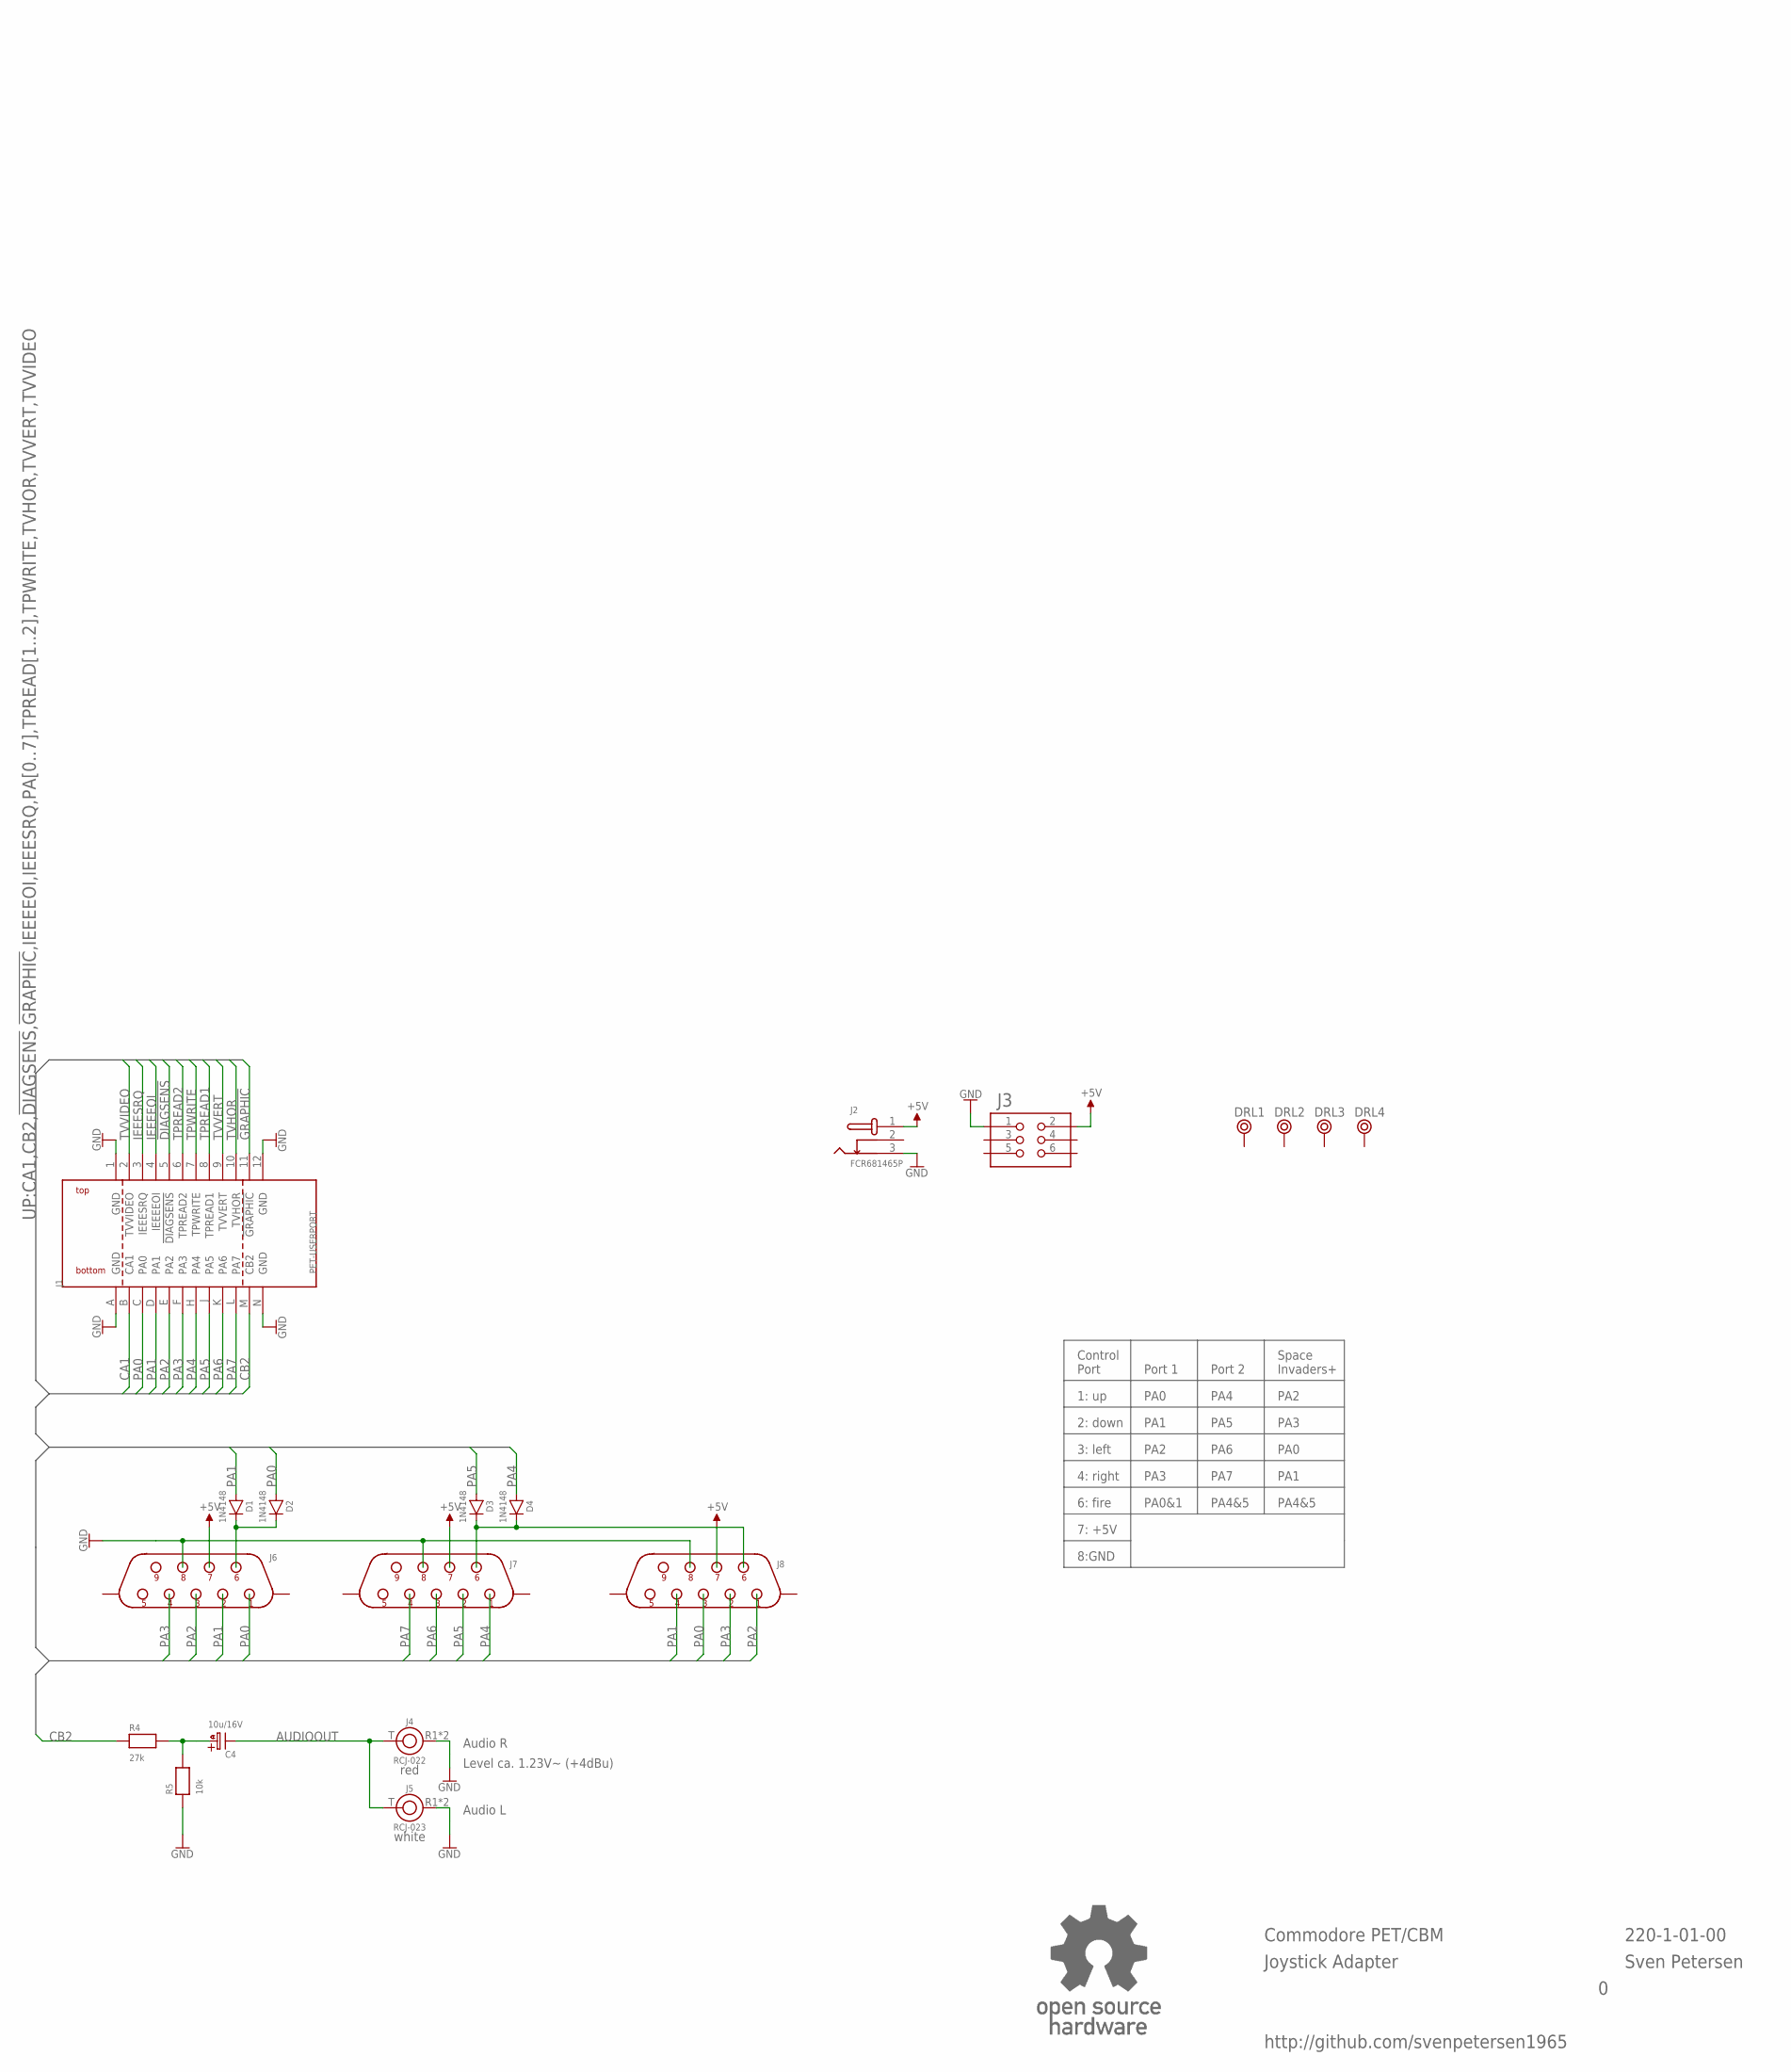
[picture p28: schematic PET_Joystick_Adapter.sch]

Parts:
C4: 10u/16V; C5,0/2,0
D1, D2, D3, D4: 1N4148; DO-35/3
DRL1, DRL2, DRL3, DRL4: BOHR3,5
J1: PET-USERPORT; USERPORT
J2: FCR681465P
J3: 2X03WV
J4: RCJ-022; RCJ-02X
J5: RCJ-023; RCJ-02X
J6, J7: DS09M-H-CL; DS9M-H
J8: DS09M-V-CL; DS09M-V
R4: 27k; R-10
R5: 10k; R-10
U$2: OPEN_SOURCE_HW; OPENHW

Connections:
!DIAGSENS: J1.5 (!DIAGSENS)
!GRAPHIC: J1.11 (!GRAPHIC)
+5V: J2.1, J3.2, J6.7, J7.7, J8.7
AUDIOOUT: C4.K (-), J4.T, J5.T
CA1: J1.B (CA1)
CB2: J1.M (CB2), R4.1
GND: J1.1 (GND), J1.12 (GND), J1.A (GND), J1.N (GND), J2.3, J3.1, J4.R1 (R), J4.R2 (R), J5.R1 (R), J5.R2 (R), J6.8, J7.8, J8.8, R5.1
IEEEEOI: J1.4 (IEEEEOI)
IEEESRQ: J1.3 (IEEESRQ)
unnamed: C4.A (+), R4.2, R5.2
unnamed: D1.K, D2.K, J6.6
unnamed: D3.K, D4.K, J7.6, J8.6
PA0: D2.A, J1.C (PA0), J6.1, J8.3
PA1: D1.A, J1.D (PA1), J6.2, J8.4
PA2: J1.E (PA2), J6.3, J8.1
PA3: J1.F (PA3), J6.4, J8.2
PA4: D4.A, J1.H (PA4), J7.1
PA5: D3.A, J1.J (PA5), J7.2
PA6: J1.K (PA6), J7.3
PA7: J1.L (PA7), J7.4
TPREAD1: J1.8 (TPREAD1)
TPREAD2: J1.6 (TPREAD2)
TPWRITE: J1.7 (TPWRITE)
TVHOR: J1.10 (TVHOR)
TVVERT: J1.9 (TVVERT)
TVVIDEO: J1.2 (TVVIDEO)

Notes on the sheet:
http://github.com/svenpetersen1965
Commodore PET/CBM
Joystick Adapter
Sven Petersen
220-1-01-00
red
white
Audio R
Audio L
Level ca. 1.23V~ (+4dBu)
1: up
2: down
3: left
4: right
6: fire
7: +5V
8:GND
Control Port
Port 1
Port 2
Space Invaders+
PA4&5
PA0
PA1
PA2
PA3
PA4
PA5
PA6
PA7
PA0&1

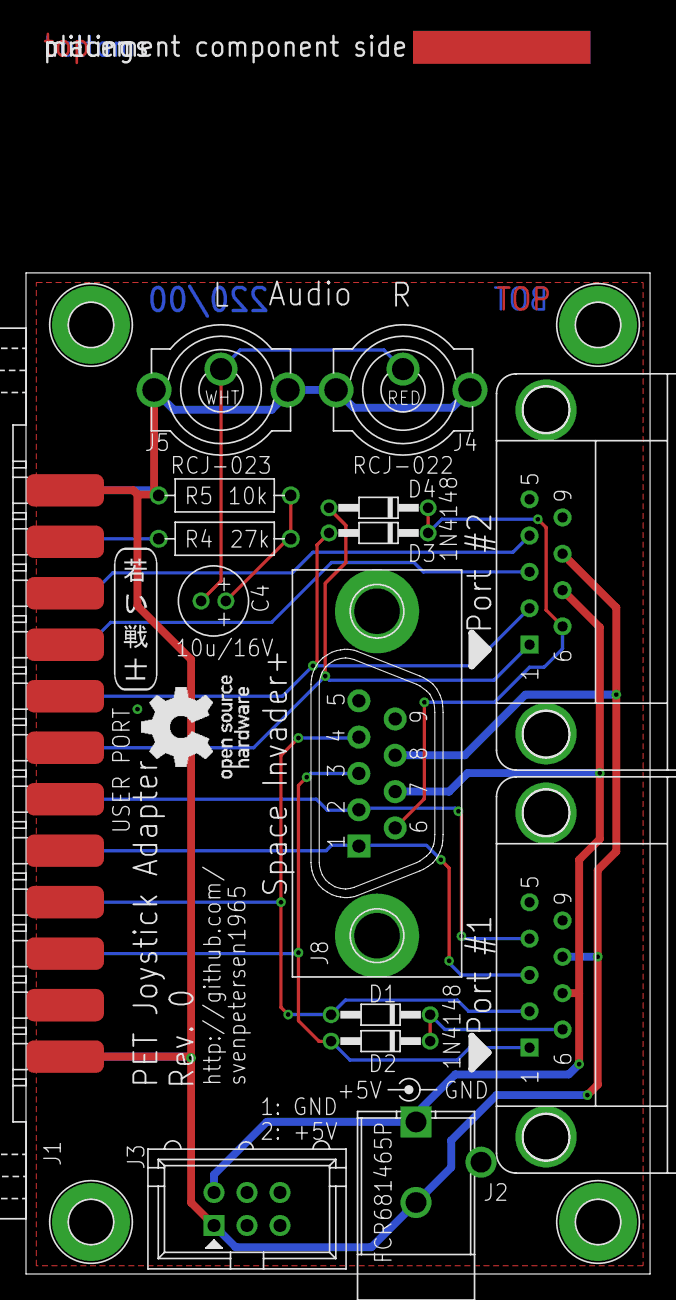
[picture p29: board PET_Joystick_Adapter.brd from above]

Board: 2 copper layers, 48.0 x 77.0 mm, 23 parts (0 on the bottom side), 15 nets.

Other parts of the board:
U$11: 2LAYER
U$22: PCB-TITLE/
U$26: SVEN_TAG
